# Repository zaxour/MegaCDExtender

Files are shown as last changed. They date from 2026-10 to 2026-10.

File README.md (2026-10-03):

# MegaCDExtender
A solution to allow for easier testing of Sega/Mega CD units

Ever had to troubleshoot a Mega CD? Everyone knows what a chore it can be to have to have the Genesis/MD sitting precariously above, making it difficult to probe the board. 

This is a simple extension board to allow for running the Genesis/MD off to the side, leaving the board open for analysis!

PCB's should be ordered in 1.6mm thickness. HASL is fine, ENIG would be a better choice. Make sure to do beveling for the CD side PCB.

*** USE THIS AT YOUR OWN RISK. I HAVE TESTED THIS AND IT WORKS PERFECTLY, BUT I AM NOT RESPONSIBLE FOR IMPROPER ASSEMBLY CAUSING DAMAGE ***

## Materials Needed
1 MD Side PCB

1 CD Side PCB 

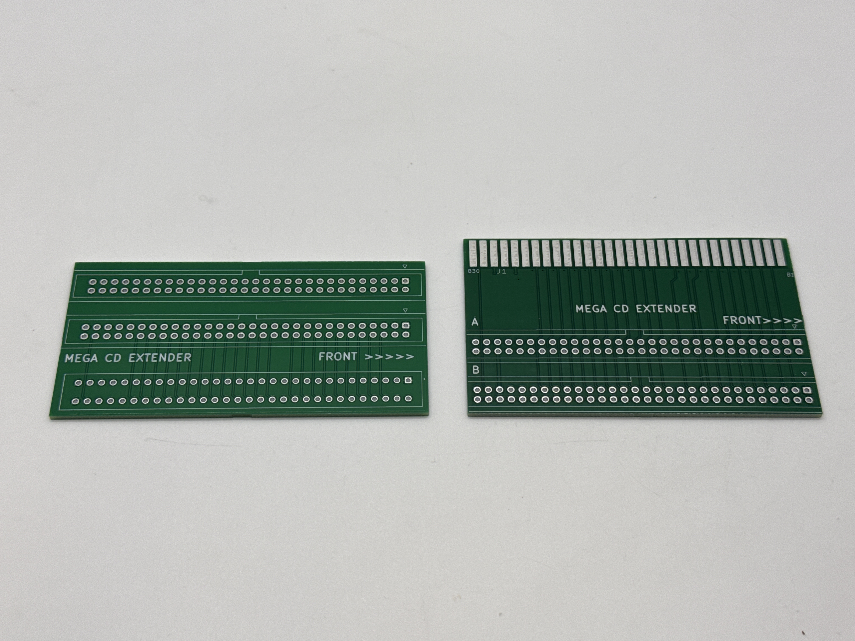
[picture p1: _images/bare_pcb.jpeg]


4 60 (2x30) pin IDC connectors (https://www.aliexpress.us/item/3256808989392536.html)

1 60 pin RIGHT ANGLE Card Edge Connector (notches should be oriented like the photo) (https://www.aliexpress.us/item/3256803460752665.html)

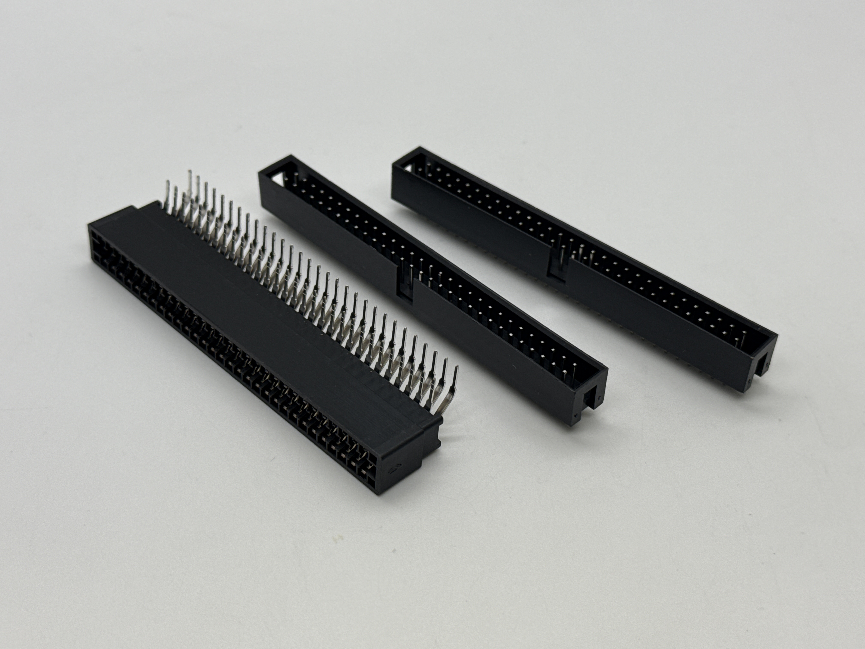
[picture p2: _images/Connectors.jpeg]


2 60 pin IDC cables (https://www.aliexpress.us/item/3256809525176986.html)

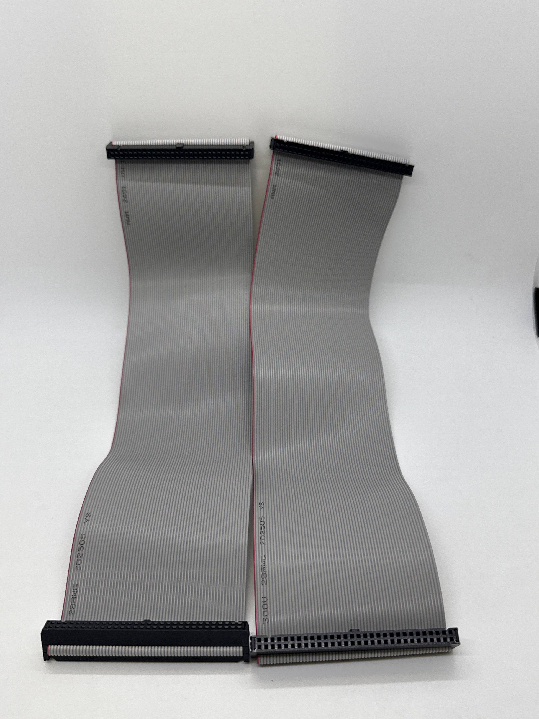
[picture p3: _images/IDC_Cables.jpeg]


## Assembly Instructions

### 1. Assemble the IDC and Card Edge connectors
Make sure the notches on the IDC connectors align with the indicated notch on the silkscreen.
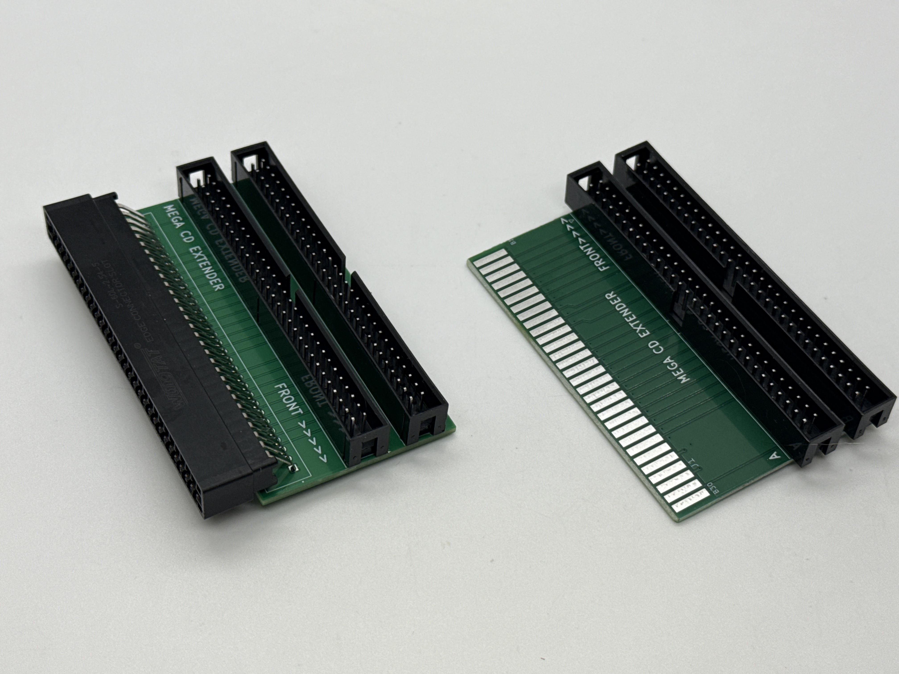
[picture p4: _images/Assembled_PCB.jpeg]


### 2. Insert The First IDC cable as shown
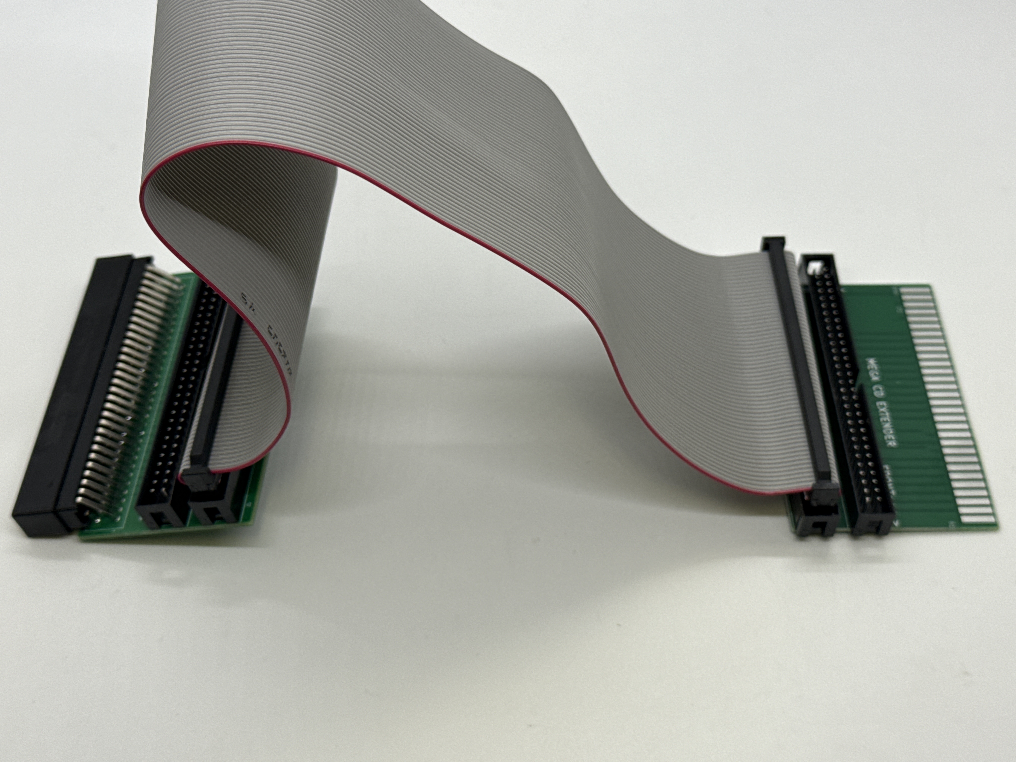
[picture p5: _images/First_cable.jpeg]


### 3. Insert the Second IDC cable
This completes the assembly. It is recommended to verify pin to pin connectivity from the 60 pin slot on the MD side to the 60 pin edge on the CD side.
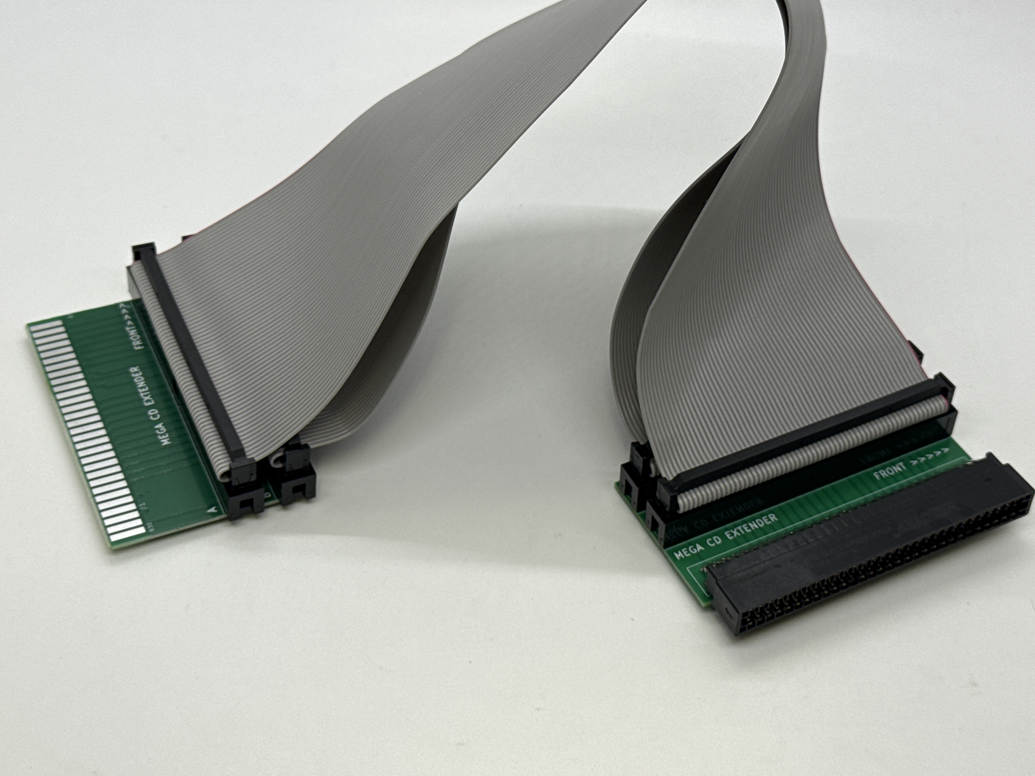
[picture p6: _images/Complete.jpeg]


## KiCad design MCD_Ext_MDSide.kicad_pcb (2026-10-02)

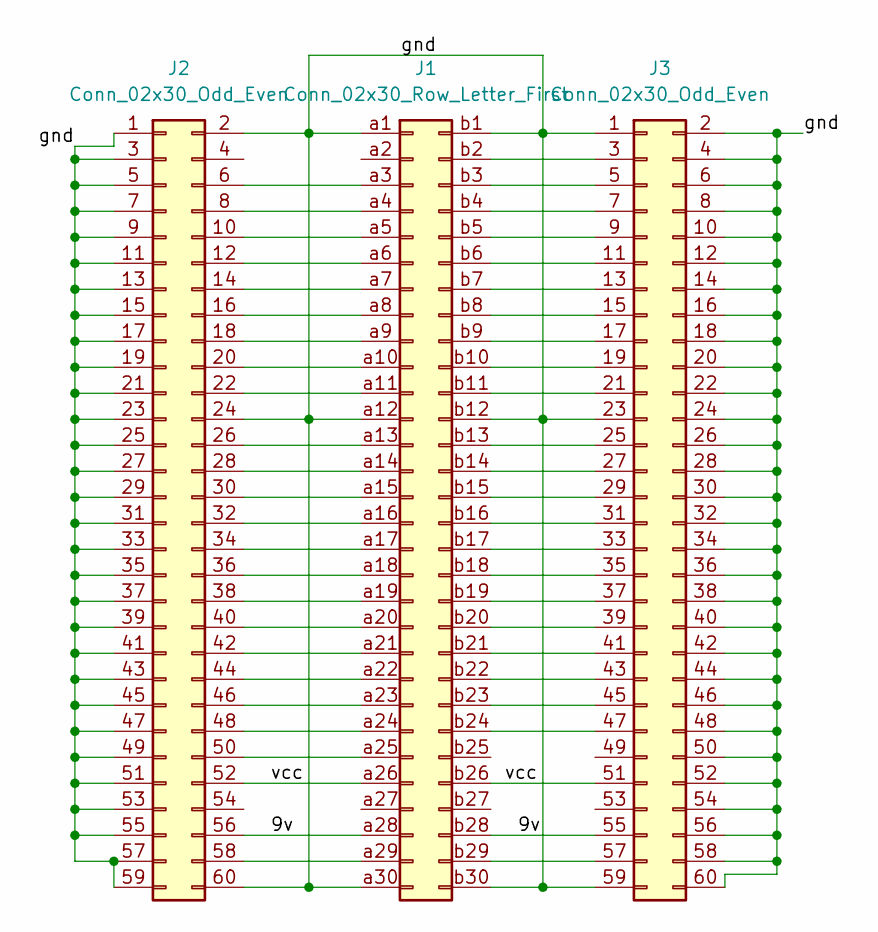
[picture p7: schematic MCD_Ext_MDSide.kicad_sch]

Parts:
J1: Conn_02x30_Row_Letter_First; Edge_60P
J2, J3: Conn_02x30_Odd_Even; IDC-Header_2x30_P2.54mm_Vertical

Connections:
/9v: J1.a28, J1.b28, J2.56, J3.55
/gnd: J1.a1, J1.a12, J1.a30, J1.b1, J1.b12, J1.b30, J2.1, J2.2, J2.3, J2.5, J2.7, J2.9, J2.11, J2.13, J2.15, J2.17, J2.19, J2.21, J2.23, J2.24, J2.25, J2.27, J2.29, J2.31, J2.33, J2.35, J2.37, J2.39, J2.41, J2.43, J2.45, J2.47, J2.49, J2.51, J2.53, J2.55, J2.57, J2.59, J2.60, J3.1, J3.2, J3.4, J3.6, J3.8, J3.10, J3.12, J3.14, J3.16, J3.18, J3.20, J3.22, J3.23, J3.24, J3.26, J3.28, J3.30, J3.32, J3.34, J3.36, J3.38, J3.40, J3.42, J3.44, J3.46, J3.48, J3.50, J3.52, J3.54, J3.56, J3.58, J3.59, J3.60
/vcc: J1.a26, J1.b26, J2.52, J3.51
unnamed: J1.a3, J2.6
unnamed: J1.a4, J2.8
unnamed: J1.a5, J2.10
unnamed: J1.a6, J2.12
unnamed: J1.a7, J2.14
unnamed: J1.a8, J2.16
unnamed: J1.a9, J2.18
unnamed: J1.a10, J2.20
unnamed: J1.a11, J2.22
unnamed: J1.a13, J2.26
unnamed: J1.a14, J2.28
unnamed: J1.a15, J2.30
unnamed: J1.a16, J2.32
unnamed: J1.a17, J2.34
unnamed: J1.a18, J2.36
unnamed: J1.a19, J2.38
unnamed: J1.a20, J2.40
unnamed: J1.a21, J2.42
unnamed: J1.a22, J2.44
unnamed: J1.a23, J2.46
unnamed: J1.a24, J2.48
unnamed: J1.a25, J2.50
unnamed: J1.a29, J2.58
unnamed: J1.b2, J3.3
unnamed: J1.b3, J3.5
unnamed: J1.b4, J3.7
unnamed: J1.b5, J3.9
unnamed: J1.b6, J3.11
unnamed: J1.b7, J3.13
unnamed: J1.b8, J3.15
unnamed: J1.b9, J3.17
unnamed: J1.b10, J3.19
unnamed: J1.b11, J3.21
unnamed: J1.b13, J3.25
unnamed: J1.b14, J3.27
unnamed: J1.b15, J3.29
unnamed: J1.b16, J3.31
unnamed: J1.b17, J3.33
unnamed: J1.b18, J3.35
unnamed: J1.b19, J3.37
unnamed: J1.b20, J3.39
unnamed: J1.b21, J3.41
unnamed: J1.b22, J3.43
unnamed: J1.b23, J3.45
unnamed: J1.b24, J3.47
unnamed: J1.b29, J3.57

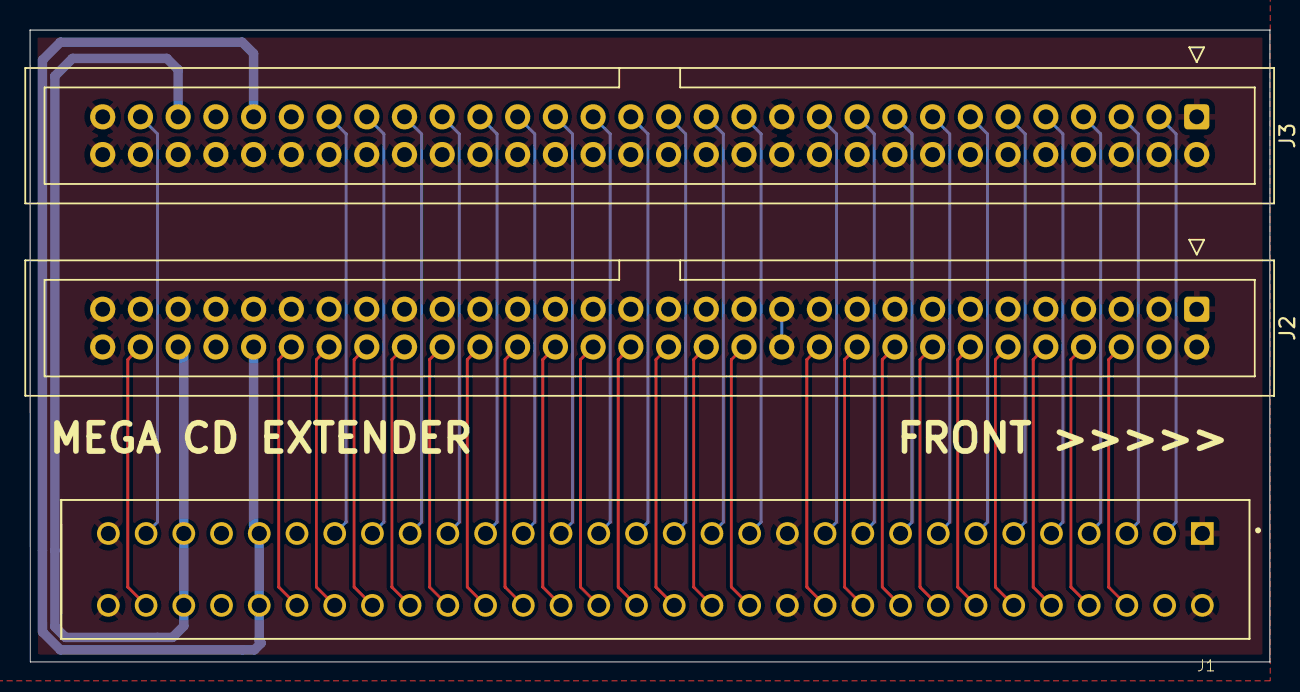
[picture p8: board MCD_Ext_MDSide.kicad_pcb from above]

Board: 2 copper layers, 83.5 x 42.5 mm, 3 parts (0 on the bottom side), 49 nets.
